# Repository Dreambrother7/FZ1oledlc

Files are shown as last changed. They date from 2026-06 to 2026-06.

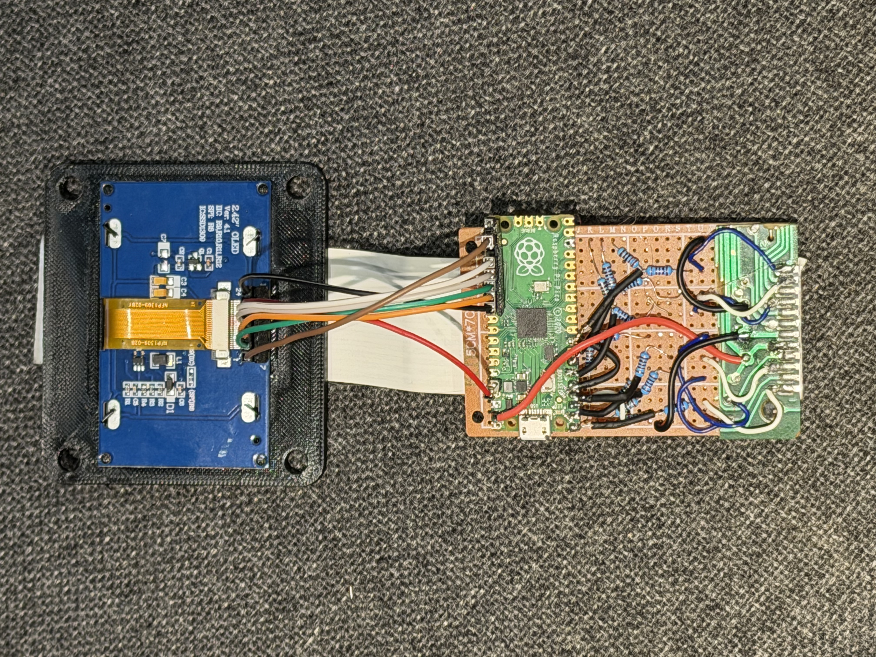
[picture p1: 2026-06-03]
images/Pico and display wiring.jpeg

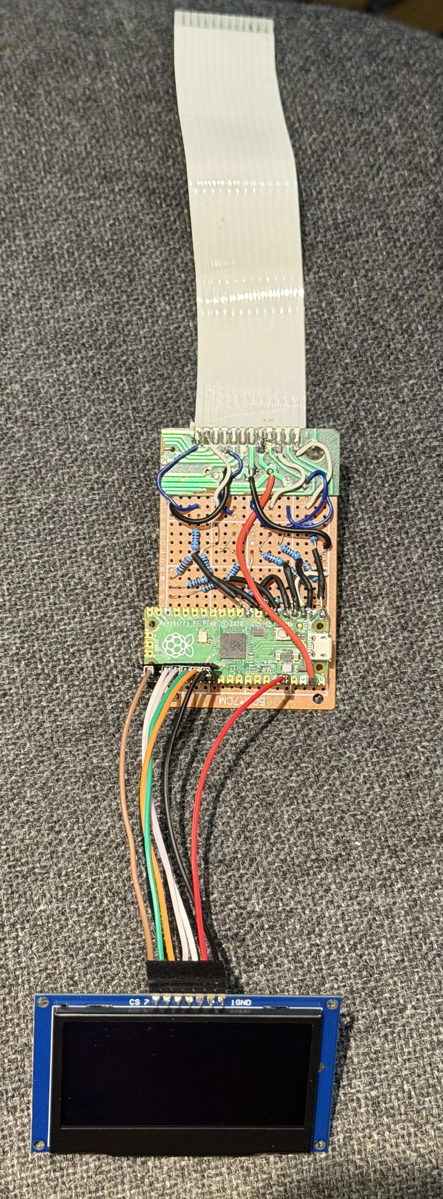
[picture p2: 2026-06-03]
images/Full display adapter.jpeg

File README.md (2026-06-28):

# Casio FZ-Series OLED Display Replacement

A low cost DIY replacement display for the Casio FZ-1, FZ-10M, FZ-20M, and related VZ-series devices using a Raspberry Pi Pico and a generic SSD1309 OLED module.

This project replaces the original ageing Casio FZ-series LCD with inexpensive, readily available parts. The goal is to make the repair practical and affordable for ordinary owners: no rare display module, no specialist programmable logic, and no expensive donor parts. There are now two supported build methods: a hand-wired version using a 3D printed OLED mount, and a Deftaudio PCB version that carries the Pico and OLED on a purpose-made board.

> Project status: working prototype for Casio FZ-series hardware. The firmware renders correctly on tested FZ hardware, including Deftaudio PCB testing on FZ-1, FZ-10 / FZ-20 units. Related VZ-series support is planned for a future update but is not implemented yet. More long-term testing is still in progress. Please report any observed issues or unwanted behaviour.

## Current Revision

Documentation revision: `v0.2.0`

Recent additions since the original working prototype:

- Standalone OLED test firmware for checking the screen before connecting the FZ-1 display bus.
- Five-minute idle screensaver in the main FZ-1 display firmware.
- Deftaudio Pico OLED PCB support, including KiCad files and a ready-to-upload Gerber zip.
- Separate `original` and `deftaudio_pcb` firmware variants for the two hardware methods.
- Experimental Pico 2 / RP2350 builds. These build successfully, but should be treated as untested until confirmed on real hardware.

## Why This Exists

Many Casio FZ-1 units still sound wonderful, but the original display hardware is now a weak point. Replacement displays are difficult to source, and many modern display modules do not speak the same protocol as the original LCD.

This project keeps the synthesizer mostly original while replacing only the display system. The FZ-1 still drives its original display bus; the Pico listens to that bus, decodes the commands, and renders the same content onto a modern OLED.

## Why A Raspberry Pi Pico?

The RP2040 is especially well suited to this job because of its PIO peripheral.

The FZ-1 display bus is a timing-sensitive 4-bit parallel interface with separate clock, chip-enable, and command/data signals. A normal microcontroller interrupt loop can easily miss edges or jitter under load. The Pico's PIO state machine can sample the bus independently of the CPU, while DMA moves captured samples into memory. The main firmware can then decode and render the display data without needing to bit-bang the vintage bus directly.

In short:

- PIO gives reliable edge-triggered bus capture.
- DMA keeps capture overhead low.
- Hardware SPI drives the OLED quickly.
- The Pico is cheap, common, and easy to flash by copying a UF2 file.

## Repository Contents

- `main.cpp` - Main FZ-1 display firmware, protocol parser, renderer, and screensaver.
- `oled_ssd1309.cpp` / `oled_ssd1309.h` - Shared SSD1309 OLED driver.
- `oled_test.cpp` - Standalone OLED wiring/display test firmware.
- `fz1_capture.pio` - PIO program for sampling the FZ-1 display bus.
- `font.h` - 256-character FZ-compatible 6x8 font table.
- `FZ1wiring-original.md` - Wiring reference for the original hand-wired build and 3D printed mount.
- `FZ1wiring-deftaudio-pcb.md` - Wiring and bring-up reference for the Deftaudio PCB build.
- `images/` - Photos of the original display board, cut connector board, assembled electronics, and installed working display.
- `3D printed mount/` - STL files for printing the display mounting plate and brackets.
- `pcb/deftaudio_pico_oled/` - Deftaudio KiCad PCB project and exported Gerber/drill manufacturing files.
- `pcb/deftaudio_connector_adapters/` - Deftaudio KiCad projects and Gerber zips for optional FZ-series IDC connector adapter boards.

## Image References

- `images/Original display board.jpeg` - Original FZ-1 display board before modification.
- `images/Original connector before cutting.jpeg` - Original connector area before cutting the donor display board.
- `images/Pico and display wiring.jpeg` - Pico, OLED, and resistor divider wiring.
- `images/Full display adapter.jpeg` - Assembled display adapter wiring.
- `images/Boot logo.jpeg` - Working OLED showing the FZ-1 boot logo.
- `images/Main menu.jpeg` - Working OLED showing the FZ-1 main menu.

## Build Options

The Pico passively listens to the FZ-1 display bus. It does not replace or emulate the FZ-1 CPU; it only translates the original display traffic into SSD1309 OLED drawing commands.

There are two supported hardware approaches.

### Original Hand-Wired Method

This is the original prototype method. It reuses the FZ-1 display connector or a cut-down section of the original display board, wires the Pico by hand through resistor dividers, and mounts the OLED with the 3D printed parts in `3D printed mount/`.

Use:

- Wiring file: `FZ1wiring-original.md`
- Main firmware: `FZ1_display_original_*.uf2`
- OLED test firmware: `FZ1_oled_test_original_*.uf2`

### Deftaudio PCB Method

This method uses the Deftaudio Pico OLED PCB. The board can be ordered by uploading `pcb/deftaudio_pico_oled/Pico_FZ1_OLED_PCB_gerbers.zip` to a PCB manufacturer such as PCBWay or a similar service. The loose Gerber/drill files are also included in `pcb/deftaudio_pico_oled/export1.0/`. The Pico and OLED attach to the PCB, and the PCB assembly then mounts directly in the synth.

Deftaudio also provides optional IDC connector adapter boards for connecting the synth display harness to the Pico OLED PCB. The FZ-1 adapter and the FZ-10M/FZ-20M/VZ-10M adapter are included in `pcb/deftaudio_connector_adapters/`, each with KiCad source files and a ready-to-upload Gerber zip.

Use:

- Wiring file: `FZ1wiring-deftaudio-pcb.md`
- PCB files: `pcb/deftaudio_pico_oled/`
- Optional connector adapter PCB files: `pcb/deftaudio_connector_adapters/`
- Main firmware: `FZ1_display_deftaudio_pcb_*.uf2`
- OLED test firmware: `FZ1_oled_test_deftaudio_pcb_*.uf2`

## Firmware Variants

The two hardware methods need different firmware because the OLED wiring and physical orientation are not the same.

| Variant | Use this for | OLED DC/A0 | OLED RES/RST | OLED orientation |
| --- | --- | --- | --- | --- |
| `original` | Hand wiring and the 3D printed mount in this repository | GP20 | GP21 | Original orientation |
| `deftaudio_pcb` | First Deftaudio PCB layout based on the earlier wiring guide | GP21 | GP20 | Rotated 180 degrees |

Important: disconnect the Pico from USB when powering it from the FZ-1 `VSYS` connection, unless your hardware setup specifically prevents back-powering.

For Pico 2 testing, the firmware builds with `PICO_BOARD=pico2` using the same GP0-GP6 FZ-1 bus pin mapping. The OLED pin mapping still depends on the selected `original` or `deftaudio_pcb` firmware variant.

## Parts

Core parts for both methods:

- Raspberry Pi Pico or compatible RP2040 Pico board.
- Raspberry Pi Pico 2 for experimental RP2350 testing.
- 128x64 SPI OLED module using SSD1309 controller.

For the original hand-wired method:

- Casio FZ-1 with original display connector/board available.
- 1k and 2k resistors for voltage dividers on the FZ-1 bus signals.
- Hookup wire, soldering tools, and basic mounting hardware.
- 3D printed OLED mount and brackets from `3D printed mount/`.

For the Deftaudio PCB method:

- PCB ordered from `pcb/deftaudio_pico_oled/Pico_FZ1_OLED_PCB_gerbers.zip`.
- Optional connector adapter PCB ordered from the matching Gerber zip in `pcb/deftaudio_connector_adapters/`.
- Components and headers required by the Deftaudio PCB design.
- Soldering tools and mounting hardware appropriate to the PCB assembly.

The prototype uses resistor dividers rather than active level-shifter ICs. Bidirectional auto-sensing level shifters were originally tested and proved incompatible with the FZ-1 display bus.

Pico 2 / RP2350 builds are provided for experimenters, but they have not yet been confirmed on real FZ-1 hardware. If you are building the mod today, use the resistor-divider wiring shown in the wiring guide for your hardware method. Do not connect FZ-1 5V display-bus signals directly to any Pico 2 pin unless you have checked the exact board, power conditions, and GPIO limits against the official [RP2350 datasheet](https://pip.raspberrypi.com/documents/RP-008373-DS-2-rp2350-datasheet.pdf) and [Pico 2 datasheet](https://pip.raspberrypi.com/documents/RP-008299-DS-pico-2-datasheet.pdf). One concern is that the RP2350 pins are only 5V tolerant after power on and if the FZ pushes 5V to the pins before power on is complete, damage is possible.

## Physical Installation

For the original hand-wired method, the prototype reuses part of the original display board as a connector breakout. The original display PCB is cut so that the FZ-1 ribbon connector section can be retained, and wires are soldered to that retained connector section. The OLED is held in a custom 3D printed mount designed to match the shape of the display module and closely follow the original FZ-1 mounting plate.

For the Deftaudio PCB method, order the main board by uploading `pcb/deftaudio_pico_oled/Pico_FZ1_OLED_PCB_gerbers.zip`, assemble the Pico and OLED onto the PCB, then install the completed PCB assembly in the synth. If you want a PCB adapter for the synth-side display connector, order the matching board from `pcb/deftaudio_connector_adapters/`: one design is for FZ-1, and the other is for FZ-10M/FZ-20M/VZ-10M. This avoids the large point-to-point wiring loom used by the original prototype method.

Photos and installation references should be placed in `images/`. 3D printable files should be placed in `3D printed mount/`.

## Firmware Overview

The firmware has five main jobs:

1. Initialize the SSD1309 OLED over SPI.
2. Use PIO to sample the FZ-1 display bus on PH2 clock edges while #CE is active.
3. Decode the FZ-1 command/data packets.
4. Render text and graphics to the OLED using the FZ-1 font.
5. Enter a framebuffer-backed idle screensaver after five minutes without FZ-1 display content changes.

Implementation details:

- FZ-1 data lines are active-low.
- The physical data wiring is reversed, so decoded nibbles are bit-reversed with a lookup table.
- Hardware testing showed that each nibble is captured twice in adjacent pairs. The parser conservatively collapses packets only when every adjacent pair matches.
- The FZ-1 cursor arrow uses extended font glyph `0xEE`, so the renderer uses the full 256-entry font table.
- The screensaver draws a sparse twinkling star field, then restores the last real FZ-1 display image before processing new bus activity.

## Building The Firmware

Install the Raspberry Pi Pico SDK and an ARM embedded GCC toolchain. On macOS, the tested working setup for this project uses the `gcc-arm-embedded` Homebrew cask.

Configure and build:

```bash
cmake -S . -B build -DPICO_SDK_PATH=/path/to/pico-sdk
cmake --build build
```

The default Pico build produces:

```text
build/FZ1_display_original.uf2
build/FZ1_display_deftaudio_pcb.uf2
build/FZ1_oled_test_original.uf2
build/FZ1_oled_test_deftaudio_pcb.uf2
```

To build for Pico 2:

```bash
cmake -S . -B build-pico2 -DPICO_SDK_PATH=/path/to/pico-sdk -DPICO_BOARD=pico2
cmake --build build-pico2
```

That produces:

```text
build-pico2/FZ1_display_original.uf2
build-pico2/FZ1_display_deftaudio_pcb.uf2
build-pico2/FZ1_oled_test_original.uf2
build-pico2/FZ1_oled_test_deftaudio_pcb.uf2
```

## Flashing The Pico

The easiest route is to download a prebuilt UF2 file from the repository's GitHub Releases page:

- `FZ1_display_original_pico.uf2` - Main firmware for Raspberry Pi Pico using the original hand-wired method.
- `FZ1_display_deftaudio_pcb_pico.uf2` - Main firmware for Raspberry Pi Pico using the first Deftaudio PCB layout.
- `FZ1_oled_test_original_pico.uf2` - OLED wiring test for Raspberry Pi Pico using the original hand-wired method.
- `FZ1_oled_test_deftaudio_pcb_pico.uf2` - OLED wiring test for Raspberry Pi Pico using the first Deftaudio PCB layout.
- `FZ1_display_original_pico2.uf2` - Experimental main firmware for Raspberry Pi Pico 2 using the original hand-wired method.
- `FZ1_display_deftaudio_pcb_pico2.uf2` - Experimental main firmware for Raspberry Pi Pico 2 using the first Deftaudio PCB layout.
- `FZ1_oled_test_original_pico2.uf2` - OLED wiring test for Raspberry Pi Pico 2 using the original hand-wired method.
- `FZ1_oled_test_deftaudio_pcb_pico2.uf2` - OLED wiring test for Raspberry Pi Pico 2 using the first Deftaudio PCB layout.

If you are modifying the firmware, build it locally and use the UF2 produced in your build directory.

1. Hold the Pico `BOOTSEL` button while connecting it over USB.
2. The Pico appears as a USB mass-storage device.
3. Copy the correct `FZ1_oled_test_*.uf2` file first if you are doing display-side bring-up, or the correct `FZ1_display_*.uf2` file for normal use.
4. The Pico reboots automatically into the firmware.

Once installed in the FZ-1, the firmware is silent: there is no boot test pattern and no serial output.

Maintainers can create a GitHub Release by pushing a version tag such as `v0.1.0`. The release workflow builds Pico and Pico 2 UF2 files and attaches them to the release automatically.

## OLED Wiring Test Firmware

The repository builds a special OLED test firmware for each hardware method. Use it before connecting the FZ-1 display bus, or before installing the Deftaudio PCB assembly in the synth, to confirm that the Pico can drive the OLED correctly.

Choose the test firmware that matches the hardware:

- Original hand-wired build: `FZ1_oled_test_original_pico.uf2` or `FZ1_oled_test_original_pico2.uf2`
- Deftaudio PCB build: `FZ1_oled_test_deftaudio_pcb_pico.uf2` or `FZ1_oled_test_deftaudio_pcb_pico2.uf2`

The test firmware cycles through:

- A full-screen checkerboard.
- A text screen showing `FZ-1 OLED TEST`, the selected firmware variant, and `SSD1309 SPI OK`.
- A full-white screen.
- A blank screen.

If this test works but the main FZ-1 firmware does not, the OLED side is probably good and the next area to check is the FZ-1 bus connection or the selected firmware variant.

## Testing

Basic checks:

- OLED should clear at startup.
- FZ-1 boot screen should render correctly.
- Main menu text should be aligned and readable.
- Cursor arrow should appear and move with the FZ-1 cursor buttons.
- Switching pages and menus should not leave stale pixels or corrupt text.
- After five minutes without FZ-1 display content changes, the screen should switch to a sparse twinkling star field and then restore the previous FZ-1 screen on the next real display update.

If the display is blank, verify power, common ground, OLED SPI wiring, and reset/DC pins.

If the display is garbled, verify the FZ-1 bus wiring order, resistor dividers, and the GP0-GP6 contiguous capture wiring.

## Safety Notes

This modification requires opening the synthesizer and working near vintage electronics. Work carefully, disconnect power before soldering, and double-check the 5V-to-3.3V dividers before connecting the Pico.

Original Pico/RP2040 GPIOs are not 5V tolerant.

Pico 2/RP2350 direct 5V input testing is experimental. Do not assume that a wiring change is safe unless the exact board, power sequence, and GPIO limits have been checked against the official Raspberry Pi documentation.

## Credits

Special thanks to [Deftaudio](https://github.com/Deftaudio) for developing the Pico OLED PCB, allowing the PCB files to be hosted in this repository, and testing the Deftaudio PCB firmware on real Casio FZ-1, FZ-10, and FZ-20 hardware. That work makes the PCB build a much more practical option for other users.

This project was also developed with reference to the OLED upgrade material preserved in the [Deftaudio/Casio-FZ-1 repository](https://github.com/Deftaudio/Casio-FZ-1). Those files include a copy of the original AVR-based FZ/VZ OLED design by Dmitri Sytov, known as Dmitrins, who shared it on the [Yamahamusicians forum](https://yamahamusicians.com/forum/viewtopic.php?t=10666&start=240). The RP2040 firmware in this repository ports the concept to a Raspberry Pi Pico using PIO, DMA, and SPI.

## License

This project is released under the MIT License. See `LICENSE` for the full license text.

Third-party reference material is credited above and remains the work of its original authors.

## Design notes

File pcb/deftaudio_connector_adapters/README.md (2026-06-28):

# Deftaudio Connector Adapter PCBs

This folder contains Deftaudio's optional IDC connector adapter PCB designs for FZ-series OLED installations.

These boards are separate from the main Pico OLED PCB in `pcb/deftaudio_pico_oled/`. They provide model-specific connector adapter hardware for the synth-side display harness.

## Included Boards

| Folder | Use for | Upload-ready Gerber zip |
| --- | --- | --- |
| `fz1_oled_IDC_adapter_v2/` | Casio FZ-1 | `fz1_oled_IDC_adapter_v2_gerbers.zip` |
| `fz10m_fz20m_vz10m_oled_IDC_adapter/` | Casio FZ-10M, FZ-20M, and VZ-10M | `fz10m_fz20m_vz10m_oled_IDC_adapter_gerbers.zip` |

Each board folder includes the KiCad project files, local KiCad library files, loose Gerber/drill files in `export1.0/`, and a ready-to-upload Gerber zip for PCB manufacturers such as PCBWay.

Use the connector adapter that matches the synth model. The main firmware variant for the Deftaudio PCB method is still `deftaudio_pcb`.

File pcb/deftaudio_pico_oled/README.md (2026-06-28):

# Deftaudio Pico OLED PCB

This folder contains the Deftaudio Pico OLED PCB files for the Casio FZ-1 OLED replacement.

## Contents

- `Pico_FZ1_OLED_PCB.kicad_pro` - KiCad project.
- `Pico_FZ1_OLED_PCB.kicad_sch` - KiCad schematic.
- `Pico_FZ1_OLED_PCB.kicad_pcb` - KiCad PCB layout.
- `Pico_FZ1_OLED_PCB_gerbers.zip` - Ready-to-upload Gerber/drill package for PCB manufacture.
- `libs/` - Local KiCad symbol/footprint support files included with the project.
- `export1.0/` - Gerber and drill files for PCB manufacture.

Upload `Pico_FZ1_OLED_PCB_gerbers.zip` to a PCB manufacturer such as PCBWay or a similar service. The loose files in `export1.0/` are included for inspection or regeneration.

Use the repository firmware variant named `deftaudio_pcb` with this board. The original hand-wired firmware is not pin/orientation compatible with this PCB.

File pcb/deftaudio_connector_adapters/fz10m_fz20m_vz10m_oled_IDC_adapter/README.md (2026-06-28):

# FZ-10M / FZ-20M / VZ-10M OLED IDC Adapter

This folder contains Deftaudio's FZ-10M, FZ-20M, and VZ-10M IDC connector adapter PCB design for the Pico OLED installation.

## Contents

- `fz10_oled_IDC_adapter.kicad_pro` - KiCad project.
- `fz10_oled_IDC_adapter.kicad_sch` - KiCad schematic.
- `fz10_oled_IDC_adapter.kicad_pcb` - KiCad PCB layout.
- `fz10m_fz20m_vz10m_oled_IDC_adapter_gerbers.zip` - Ready-to-upload Gerber/drill package for PCB manufacture.
- `export1.0/` - Loose Gerber and drill files.
- `libs/` - Local KiCad symbol/footprint support files included with the project.

Upload `fz10m_fz20m_vz10m_oled_IDC_adapter_gerbers.zip` to a PCB manufacturer such as PCBWay or a similar service.

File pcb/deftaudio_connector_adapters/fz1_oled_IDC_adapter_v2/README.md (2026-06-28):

# FZ-1 OLED IDC Adapter v2

This folder contains Deftaudio's FZ-1 IDC connector adapter PCB design for the Pico OLED installation.

## Contents

- `fz1_oled_IDC_adapter.kicad_pro` - KiCad project.
- `fz1_oled_IDC_adapter.kicad_sch` - KiCad schematic.
- `fz1_oled_IDC_adapter.kicad_pcb` - KiCad PCB layout.
- `fz1_oled_IDC_adapter_v2_gerbers.zip` - Ready-to-upload Gerber/drill package for PCB manufacture.
- `export1.0/` - Loose Gerber and drill files.
- `libs/` - Local KiCad symbol/footprint support files included with the project.

Upload `fz1_oled_IDC_adapter_v2_gerbers.zip` to a PCB manufacturer such as PCBWay or a similar service.

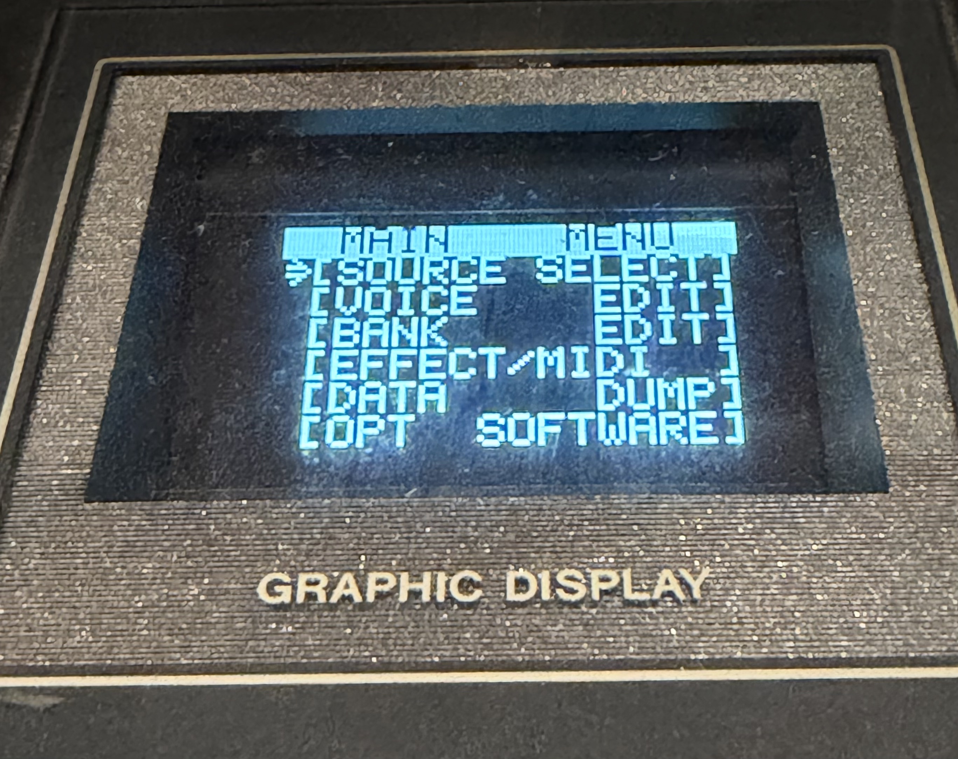
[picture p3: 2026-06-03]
images/Main menu.jpeg

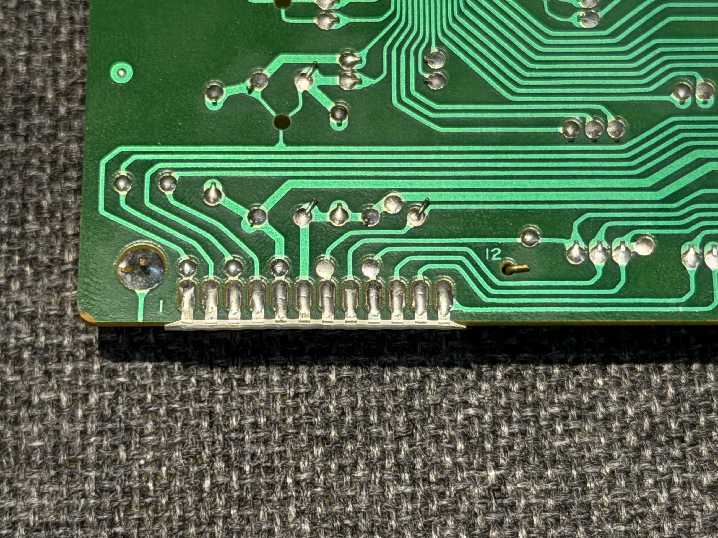
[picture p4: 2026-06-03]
images/Original connector before cutting.jpeg

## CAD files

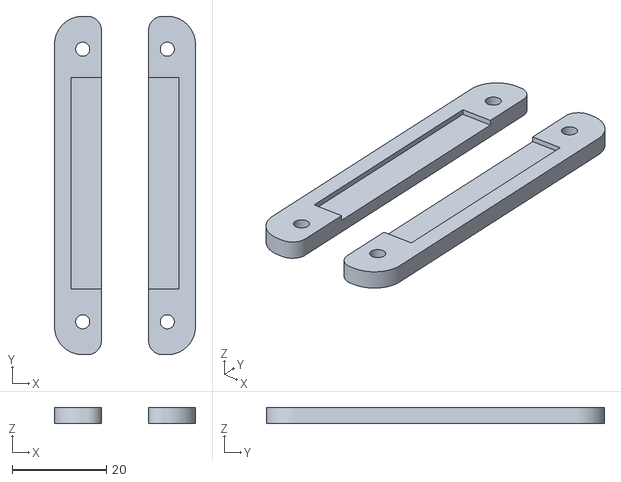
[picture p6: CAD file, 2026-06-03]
3D printed mount/FZ1OLEDbrackets.stl
30.0 x 72.0 x 3.50

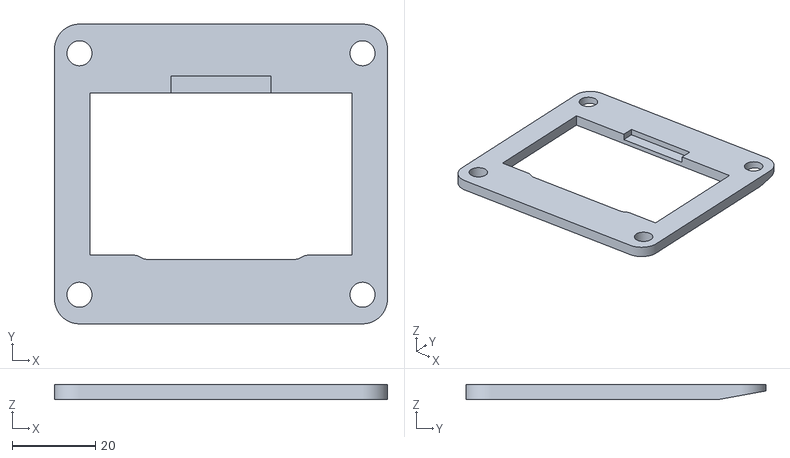
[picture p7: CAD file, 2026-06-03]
3D printed mount/FZ1OLEDmount.stl
80.0 x 72.0 x 3.50

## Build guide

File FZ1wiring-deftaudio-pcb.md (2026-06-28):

# Deftaudio PCB Build Wiring

This wiring reference is for the Deftaudio Pico OLED PCB method. The PCB files are in `pcb/deftaudio_pico_oled/`.

Use the `deftaudio_pcb` firmware files with this board.

## What The PCB Does

The Deftaudio PCB replaces most of the point-to-point wiring used by the original hand-wired build. It provides footprints/connectors for:

- Raspberry Pi Pico or Pico 2.
- SSD1309 128x64 SPI OLED module.
- FZ-1 display connector/header connection.
- The resistor-divider network used to bring FZ-1 5V bus signals down to Pico-safe logic levels.

The PCB layout mounts the OLED inverted compared with the original hand-wired build. It also routes OLED DC/A0 and RES/RST differently from the original wiring. The `deftaudio_pcb` firmware variant handles both differences in software by swapping the OLED control pins and rotating the SSD1309 output 180 degrees.

Optional synth-side IDC connector adapter boards are included in `pcb/deftaudio_connector_adapters/`:

- `fz1_oled_IDC_adapter_v2/` - FZ-1 connector adapter.
- `fz10m_fz20m_vz10m_oled_IDC_adapter/` - FZ-10M, FZ-20M, and VZ-10M connector adapter.

These adapter boards are separate from the main Pico OLED PCB. Use the adapter that matches the synth model you are installing into.

## PCB Files

The KiCad project is in:

```text
pcb/deftaudio_pico_oled/
```

The ready-to-upload manufacturing files are in:

```text
pcb/deftaudio_pico_oled/Pico_FZ1_OLED_PCB_gerbers.zip
```

The same Gerber and drill files are also available loose in:

```text
pcb/deftaudio_pico_oled/export1.0/
```

The zip file is the simplest option for PCB manufacturers such as PCBWay or similar board houses.

Optional connector adapter manufacturing zips are in:

```text
pcb/deftaudio_connector_adapters/fz1_oled_IDC_adapter_v2/fz1_oled_IDC_adapter_v2_gerbers.zip
pcb/deftaudio_connector_adapters/fz10m_fz20m_vz10m_oled_IDC_adapter/fz10m_fz20m_vz10m_oled_IDC_adapter_gerbers.zip
```

## FZ Display-Bus Header

The PCB FZ display-bus connector is `J2`, a 2x5 2.00 mm header in the KiCad files.

| J2 pin | PCB net | Function |
| --- | --- | --- |
| 1 | D4 | FZ display data D4 |
| 2 | D8 | FZ display data D8 |
| 3 | D1 | FZ display data D1 |
| 4 | D2 | FZ display data D2 |
| 5 | GND | Ground |
| 6 | +5 | FZ +5V supply |
| 7 | CE | FZ display chip enable |
| 8 | RH2 | FZ PH2 display clock; labelled `RH2` in the PCB files |
| 9 | GND | Ground |
| 10 | OP | FZ command/data select |

The PCB includes the resistor-divider network for the FZ 5V display-bus signals. The divided Pico-side nets route to the firmware capture pins as follows:

| FZ signal | Pico GPIO |
| --- | --- |
| D8 | GP0 |
| D4 | GP1 |
| D2 | GP2 |
| D1 | GP3 |
| PH2 clock / `RH2` PCB net | GP4 |
| CE | GP5 |
| OP | GP6 |

## OLED Header

The PCB OLED header is `J1`, a 1x7 2.54 mm header in the KiCad files. It is labelled for the OLED module signals:

| J1 pin | PCB/OLED signal | Pico GPIO | Purpose |
| --- | --- | --- | --- |
| 1 | GND | GND | Ground |
| 2 | 3.3V | 3V3_OUT | OLED power from Pico 3V3 |
| 3 | SCK | GP18 | SPI clock |
| 4 | SDA | GP19 | SPI MOSI data |
| 5 | RES | GP20 | OLED reset |
| 6 | DC | GP21 | OLED data/command |
| 7 | CS | GP17 | OLED chip select |

Because this board uses the Deftaudio routing and physical orientation, do not flash the `original` firmware for this method.

## Bring-Up Checklist

- Inspect the assembled board for solder bridges before installing it in the FZ-1.
- Confirm Pico orientation and OLED orientation against the PCB silkscreen/KiCad files before soldering.
- Flash `FZ1_oled_test_deftaudio_pcb_*.uf2` first and power only the Pico/OLED side to confirm the display works.
- The OLED test should cycle through checkerboard, text, white, and blank screens.
- After the OLED test passes, flash `FZ1_display_deftaudio_pcb_*.uf2`.
- Install/connect the board in the FZ-1 only after the display-side test is working.

Disconnect the Pico USB cable when powering the Pico from the FZ-1 unless your setup specifically prevents back-powering.

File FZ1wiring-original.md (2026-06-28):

# Original Hand-Wired Build Wiring

This wiring reference is for the original build method: reuse the FZ-1 display connector or connector section, wire the Pico by hand, and mount the OLED with the 3D printed parts in `3D printed mount/`.

Use the `original` firmware files with this wiring.

## FZ-1 Bus Capture

All FZ-1 bus signals are 5V logic. Each signal connected to the Pico must pass through a resistor divider:

1. Connect a 1k resistor from the FZ-1 signal to the Pico GPIO.
2. Connect a 2k resistor from that Pico GPIO to ground.

The Pico GPIOs must remain contiguous on GP0-GP6 because the PIO state machine samples them together.

| FZ-1 pin | FZ-1 signal | Divider output to Pico |
| --- | --- | --- |
| Pin 1 | D8 | GP0 |
| Pin 2 | D4 | GP1 |
| Pin 3 | D2 | GP2 |
| Pin 4 | D1 | GP3 |
| Pin 9 | PH2 clock | GP4 |
| Pin 11 | #CE | GP5 |
| Pin 12 | #OP | GP6 |

## OLED SPI

These connections are 3.3V logic and wire directly from the Pico to the SSD1309 OLED.

| OLED signal | Pico GPIO |
| --- | --- |
| CS | GP17 |
| SCK / SCL / D0 | GP18 |
| MOSI / SDA / D1 | GP19 |
| DC / A0 | GP20 |
| RES / RST | GP21 |

## Power

| Source | Destination | Purpose |
| --- | --- | --- |
| FZ-1 +5V | Pico VSYS | Pico power |
| Pico 3V3_OUT | OLED VCC / VDD | OLED power |
| FZ-1 GND | Pico GND and OLED GND | Common ground |

Disconnect the Pico USB cable when powering the Pico from FZ-1 VSYS unless your setup specifically prevents back-powering.

## Bench Checklist

- Verify about 5V on the FZ-1 power pin before connecting the Pico.
- Verify every resistor-divider output is around 3.3V or lower before connecting it to the Pico.
- Confirm GP0-GP6 are in the exact order shown above.
- Flash `FZ1_oled_test_original_*.uf2` and confirm the OLED test pattern before connecting the FZ-1 display bus.
- After the OLED test passes, flash `FZ1_display_original_*.uf2` for normal use.

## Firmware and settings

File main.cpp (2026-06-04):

#include "pico/stdlib.h"
#include "hardware/dma.h"
#include "hardware/pio.h"
#include "fz1_capture.pio.h"
#include "font.h"
#include "oled_ssd1309.h"

// FZ-1 Input pins start at GP0
#define FZ1_PIN_BASE 0
#define FZ1_PIN_COUNT 7

// FZ-1 Protocol
#define FZ_GRAPHIC  0x02
#define FZ_TEXT     0x03
#define FZ_CONTRAST 0x0C
#define FZ_RESET    0x0A

#define HORIZONTAL_OFFSET 3
#define PACKET_GAP_US 2000
#define PACKET_IDLE_FLUSH_US 50000
#define SCREENSAVER_IDLE_US (5ULL * 60ULL * 1000ULL * 1000ULL)
#define SCREENSAVER_FRAME_US 90000

// Nibble bit-reversal LUT (matching reference nibbleflip)
static const uint8_t nibbleflip[16] = {
    0x00, 0x08, 0x04, 0x0C, 0x02, 0x0A, 0x06, 0x0E,
    0x01, 0x09, 0x05, 0x0D, 0x03, 0x0B, 0x07, 0x0F
};

// Text memory for XOR operations
static uint8_t text_mem[8][24];
static uint8_t display_buf[OLED_PAGES][OLED_WIDTH];

// State from last command packet
static uint8_t last_cmd = 0;
static uint8_t last_flags = 0;
static uint8_t last_col = 0;
static uint8_t last_row = 0;

static uint32_t rng_state = 0x4F4C4544u;
static uint64_t last_display_change_time = 0;
static bool screensaver_active = false;

static uint32_t rand32() {
    rng_state ^= rng_state << 13;
    rng_state ^= rng_state >> 17;
    rng_state ^= rng_state << 5;
    return rng_state;
}

static void display_restore();

static void display_write(uint8_t page, uint8_t col, const uint8_t* data, uint8_t len) {
    if (page >= OLED_PAGES || col >= OLED_WIDTH || len == 0) {
        return;
    }
    if (col + len > OLED_WIDTH) {
        len = OLED_WIDTH - col;
    }

    bool changed = false;
    for (uint8_t i = 0; i < len; i++) {
        if (display_buf[page][col + i] != data[i]) {
            changed = true;
        }
        display_buf[page][col + i] = data[i];
    }

    if (changed) {
        last_display_change_time = time_us_64();
    }

    if (screensaver_active) {
        if (changed) {
            screensaver_active = false;
            display_restore();
        }
        return;
    }

    oled_write(page, col, data, len);
}

static void display_restore() {
    for (uint8_t page = 0; page < OLED_PAGES; page++) {
        oled_write(page, 0, display_buf[page], OLED_WIDTH);
    }
}

static void display_clear_state() {
    for (int page = 0; page < OLED_PAGES; page++) {
        for (int col = 0; col < OLED_WIDTH; col++) {
            display_buf[page][col] = 0;
        }
    }
    for (int y = 0; y < 8; y++) {
        for (int j = 0; j < 24; j++) {
            text_mem[y][j] = ' ';
        }
    }
    oled_clear();
    last_display_change_time = time_us_64();
}

static void screensaver_frame() {
    uint8_t page_buf[OLED_WIDTH];

    for (uint8_t page = 0; page < OLED_PAGES; page++) {
        for (uint8_t col = 0; col < OLED_WIDTH; col++) {
            uint8_t stars = 0;
            if ((rand32() & 0x0F) == 0) {
                stars = 1u << (rand32() & 0x07);
            }
            if ((rand32() & 0x3F) == 0) {
                stars |= 1u << (rand32() & 0x07);
            }
            page_buf[col] = stars;
        }
        oled_write(page, 0, page_buf, sizeof(page_buf));
    }
}

// ===== FZ-1 Display Functions (matching reference) =====

// Column mapping: remove the gap in the middle of the FZ-1's address space
static uint8_t calc_column(uint8_t col) {
    uint8_t col1 = col >> 1;
    uint8_t column = (col1 & 64) ? col1 : col1 + 16;
    return column + HORIZONTAL_OFFSET;
}

void display_char_fz1(uint8_t row, uint8_t col, uint8_t chr) {
    if (row >= 8 || (col / 12) >= 24) {
        return;
    }

    uint8_t column = calc_column(col);
    uint8_t page = 7 - row;

    display_write(page, column, (const uint8_t*)font[chr], 6);
    text_mem[row][col / 12] = chr;
}

void display_new_fz1(uint8_t row, uint8_t col, const uint8_t* data, uint8_t len) {
    if (row >= 8) {
        return;
    }

    uint8_t column = calc_column(col);
    uint8_t page = 7 - row;

    display_write(page, column, data, len);
}

void display_xor_fz1(uint8_t row, uint8_t col, const uint8_t* data, uint8_t len) {
    if (row >= 8 || (col / 12) >= 24) {
        return;
    }

    uint8_t column = calc_column(col);
    uint8_t page = 7 - row;
    uint8_t ch = text_mem[row][col / 12];

    uint8_t xor_buf[6];
    uint8_t xlen = (len < 6) ? len : 6;
    for (int x = 0; x < xlen; x++) {
        xor_buf[x] = font[ch][x] ^ data[x];
    }
    display_write(page, column, xor_buf, xlen);
}

// ===== FZ-1 Protocol Handlers =====

void process_command_packet(const uint8_t* nibbles, uint32_t len) {
    if (len < 6) {
        return;
    }

    // Nibbles: [0]=CMD, [1]=FLAGS, [2]=COLL, [3]=COLH, [4]=ROWL, [5]=ROWH
    last_cmd   = nibbles[0];
    last_flags = nibbles[1];
    last_col   = nibbles[2] | (nibbles[3] << 4);
    last_row   = nibbles[4] | (nibbles[5] << 4);

    // Row adjustment from flags (reference: if bit0 set and row < 4, add 4)
    if ((last_flags & 0x01) && last_row < 4)
        last_row += 4;

    // Command phase only stores parameters.
    // Character codes and graphic data arrive in the subsequent data phase.
}

void process_data_packet(const uint8_t* nibbles, uint32_t len) {
    if (len < 2) {
        return;
    }

    if (last_cmd == FZ_TEXT) {
        // Text data: 2 nibbles = character code
        uint8_t chr = nibbles[0] | (nibbles[1] << 4);
        display_char_fz1(last_row, last_col, chr);

    } else if (last_cmd == FZ_GRAPHIC) {
        // Graphic data: pairs of nibbles = pixel bytes
        uint32_t byte_len = len / 2;
        if (byte_len > 128) byte_len = 128;

        uint8_t data_bytes[128];
        for (uint32_t i = 0; i < byte_len; i++) {
            data_bytes[i] = (nibbles[i * 2] << 4) | nibbles[i * 2 + 1];
        }

        bool operation = (last_flags & 0x08) != 0;

        if (operation) {
            display_new_fz1(last_row, last_col, data_bytes, byte_len);
        } else {
            display_xor_fz1(last_row, last_col, data_bytes, byte_len);
        }
    }
}

static bool collapse_duplicated_nibbles(const uint8_t* src, uint32_t src_len, uint8_t* dst, uint32_t* dst_len) {
    if (src_len < 2 || (src_len & 1)) return false;

    for (uint32_t i = 0; i < src_len; i += 2) {
        if ((src[i] & 0x0F) != (src[i + 1] & 0x0F)) return false;
    }

    for (uint32_t i = 0; i < src_len / 2; i++) {
        dst[i] = src[i * 2];
    }
    *dst_len = src_len / 2;
    return true;
}

static void flush_packet(bool is_command_mode, const uint8_t* packet_buf, uint32_t packet_len) {
    if (packet_len == 0) return;

    static uint8_t collapsed_packet_buf[4096];
    const uint8_t* parse_buf = packet_buf;
    uint32_t parse_len = packet_len;

    if (collapse_duplicated_nibbles(packet_buf, packet_len, collapsed_packet_buf, &parse_len)) {
        parse_buf = collapsed_packet_buf;
    }

    if (is_command_mode) {
        process_command_packet(parse_buf, parse_len);
    } else {
        process_data_packet(parse_buf, parse_len);
    }
}

// ===== DMA Ring Buffer =====

#define RING_BUF_SIZE 32768
uint8_t ring_buf[RING_BUF_SIZE] __attribute__((aligned(RING_BUF_SIZE)));
int dma_chan;

void dma_init_ring(PIO pio, uint sm) {
    dma_chan = dma_claim_unused_channel(true);
    dma_channel_config c = dma_channel_get_default_config(dma_chan);

    channel_config_set_transfer_data_size(&c, DMA_SIZE_8);
    channel_config_set_read_increment(&c, false);
    channel_config_set_write_increment(&c, true);
    channel_config_set_dreq(&c, pio_get_dreq(pio, sm, false));
    channel_config_set_ring(&c, true, 15);

    dma_channel_configure(
        dma_chan,
        &c,
        ring_buf,
        (volatile uint8_t*)&pio->rxf[sm],
        0xFFFFFFFF,
        true
    );
}

// ===== Main =====

int main() {
    oled_init();
    display_clear_state();

    PIO pio = pio0;
    uint sm = 0;
    uint offset = pio_add_program(pio, &fz1_capture_program);
    fz1_capture_program_init(pio, sm, offset, 0, 7);

    pio_sm_set_enabled(pio, sm, true);
    dma_init_ring(pio, sm);

    bool is_command_mode = true;
    bool packet_active = false;
    uint32_t packet_len = 0;
    static uint8_t local_packet_buf[8192];
    uint64_t last_nibble_time = time_us_64();
    uint64_t last_screensaver_frame_time = 0;
    uint32_t ring_tail = 0;
    last_display_change_time = last_nibble_time;

    while (true) {
        uint64_t now = time_us_64();
        uint32_t ring_head = ((uint32_t)dma_hw->ch[dma_chan].write_addr - (uint32_t)ring_buf);

        if (ring_tail != ring_head) {
            uint8_t raw_sample = ring_buf[ring_tail];
            ring_tail = (ring_tail + 1) % RING_BUF_SIZE;

            uint8_t payload = raw_sample & 0x7F;

            // Decode nibble: bit-reverse (Pin1=D8→GP0, Pin4=D1→GP3) then invert (active-low)
            // Using the same nibbleflip LUT as the reference implementation
            uint8_t decoded_nibble = nibbleflip[(~payload) & 0x0F];

            // GP6 = #OP: LOW (0) = command mode, HIGH (1) = data mode
            bool current_is_command = ((payload >> 6) & 0x01) == 0;

            if (packet_active && (now - last_nibble_time > PACKET_GAP_US)) {
                flush_packet(is_command_mode, local_packet_buf, packet_len);
                packet_active = false;
                packet_len = 0;
            }

            // Detect mode change → process previous packet
            if (packet_active && current_is_command != is_command_mode) {
                flush_packet(is_command_mode, local_packet_buf, packet_len);
                packet_len = 0;
            }

            is_command_mode = current_is_command;
            packet_active = true;

            if (packet_len < sizeof(local_packet_buf)) {
                local_packet_buf[packet_len++] = decoded_nibble;
            }
            last_nibble_time = now;

        } else if (packet_active && (now - last_nibble_time > PACKET_IDLE_FLUSH_US)) {
            // Timeout → flush packet
            flush_packet(is_command_mode, local_packet_buf, packet_len);
            packet_active = false;
            packet_len = 0;
        } else if (!packet_active && now - last_display_change_time > SCREENSAVER_IDLE_US) {
            if (!screensaver_active || now - last_screensaver_frame_time > SCREENSAVER_FRAME_US) {
                screensaver_frame();
                screensaver_active = true;
                last_screensaver_frame_time = now;
            }
        }
    }
}

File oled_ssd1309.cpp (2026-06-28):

#include "oled_ssd1309.h"

#include "hardware/spi.h"
#include "pico/stdlib.h"

// SPI OLED Definitions (SSD1309)
#define SPI_PORT spi0

#ifndef OLED_PIN_CS
#define OLED_PIN_CS   17
#endif
#ifndef OLED_PIN_SDA
#define OLED_PIN_SDA  19
#endif
#ifndef OLED_PIN_SCL
#define OLED_PIN_SCL  18
#endif
#ifndef OLED_PIN_DC
#define OLED_PIN_DC   20
#endif
#ifndef OLED_PIN_RES
#define OLED_PIN_RES  21
#endif
#ifndef OLED_ROTATE_180
#define OLED_ROTATE_180 0
#endif

// SSD1309 Commands
#define OLED_DISPLAYOFF       0xAE
#define OLED_DISPLAYON        0xAF
#define OLED_SETCONTRAST      0x81
#define OLED_NORMALDISPLAY    0xA6
#define OLED_DISPLAYALLON_RESUME 0xA4
#define OLED_SETMULTIPLEX     0xA8
#define OLED_SETDISPLAYOFFSET 0xD3
#define OLED_SETDISPLAYCLOCKDIV 0xD5
#define OLED_SETPRECHARGE     0xD9
#define OLED_SETCOMPINS       0xDA
#define OLED_SETVCOMDETECT    0xDB
#define OLED_SETSTARTLINE     0x40
#define OLED_SEGREMAP         0xA0
#define OLED_SEGREMAP_INV     0xA1
#define OLED_COMSCANINC       0xC0
#define OLED_COMSCANDEC       0xC8
#define OLED_PAGEADDRSET      0xB0
#define OLED_COLUMNADDRSETH   0x10
#define OLED_COLUMNADDRSETL   0x00

void oled_send_cmd(uint8_t cmd) {
    gpio_put(OLED_PIN_CS, 0);
    gpio_put(OLED_PIN_DC, 0);
    spi_write_blocking(SPI_PORT, &cmd, 1);
    gpio_put(OLED_PIN_CS, 1);
}

void oled_send_data(uint8_t data) {
    gpio_put(OLED_PIN_CS, 0);
    gpio_put(OLED_PIN_DC, 1);
    spi_write_blocking(SPI_PORT, &data, 1);
    gpio_put(OLED_PIN_CS, 1);
}

void oled_send_data_buf(const uint8_t *buf, size_t len) {
    gpio_put(OLED_PIN_CS, 0);
    gpio_put(OLED_PIN_DC, 1);
    spi_write_blocking(SPI_PORT, buf, len);
    gpio_put(OLED_PIN_CS, 1);
}

void oled_set_cursor(uint8_t page, uint8_t col) {
    oled_send_cmd(OLED_PAGEADDRSET | page);
    oled_send_cmd(OLED_COLUMNADDRSETL | (col & 0x0F));
    oled_send_cmd(OLED_COLUMNADDRSETH | ((col >> 4) & 0x0F));
}

void oled_init() {
    spi_init(SPI_PORT, 10 * 1000 * 1000);
    gpio_set_function(OLED_PIN_SDA, GPIO_FUNC_SPI);
    gpio_set_function(OLED_PIN_SCL, GPIO_FUNC_SPI);
    gpio_init(OLED_PIN_CS); gpio_set_dir(OLED_PIN_CS, GPIO_OUT); gpio_put(OLED_PIN_CS, 1);
    gpio_init(OLED_PIN_DC); gpio_set_dir(OLED_PIN_DC, GPIO_OUT); gpio_put(OLED_PIN_DC, 0);
    gpio_init(OLED_PIN_RES); gpio_set_dir(OLED_PIN_RES, GPIO_OUT);

    gpio_put(OLED_PIN_RES, 1); sleep_ms(1);
    gpio_put(OLED_PIN_RES, 0); sleep_ms(15);
    gpio_put(OLED_PIN_RES, 1); sleep_ms(15);

    oled_send_cmd(OLED_DISPLAYOFF);

    oled_send_cmd(0xAD);  // Master Configuration
    oled_send_cmd(0x8E);  // External VCC

    oled_send_cmd(OLED_SETMULTIPLEX);
    oled_send_cmd(0x3F);  // 1/64 duty

    oled_send_cmd(OLED_SETDISPLAYOFFSET);
    oled_send_cmd(0x00);

    oled_send_cmd(OLED_SETSTARTLINE | 0x00);

    oled_send_cmd(OLED_NORMALDISPLAY);

    oled_send_cmd(OLED_SETVCOMDETECT);
    oled_send_cmd(0x3C);  // ~0.83xVCC

    oled_send_cmd(OLED_DISPLAYALLON_RESUME);

    oled_send_cmd(OLED_SETCONTRAST);
    oled_send_cmd(0x6F);

    oled_send_cmd(OLED_SETDISPLAYCLOCKDIV);
    oled_send_cmd(0xF0);  // 105Hz

    oled_send_cmd(0xD8);  // Area Color mode
    oled_send_cmd(0x05);  // Mono + low power

    oled_send_cmd(OLED_SETCOMPINS);
    oled_send_cmd(0x12);  // Alternative COM

    oled_send_cmd(OLED_SETPRECHARGE);
    oled_send_cmd(0xF2);
    oled_send_cmd(0xFF);

    oled_send_cmd(OLED_DISPLAYON);
#if OLED_ROTATE_180
    oled_send_cmd(OLED_COMSCANINC);
    oled_send_cmd(OLED_SEGREMAP_INV);
#else
    oled_send_cmd(OLED_COMSCANDEC);
    oled_send_cmd(OLED_SEGREMAP);
#endif

    sleep_ms(100);
}

void oled_write(uint8_t page, uint8_t col, const uint8_t *data, size_t len) {
    if (page >= OLED_PAGES || col >= OLED_WIDTH || len == 0) {
        return;
    }
    if (col + len > OLED_WIDTH) {
        len = OLED_WIDTH - col;
    }

    oled_set_cursor(page, col);
    oled_send_data_buf(data, len);
}

void oled_fill(uint8_t value) {
    uint8_t buf[OLED_WIDTH];
    for (int i = 0; i < OLED_WIDTH; i++) {
        buf[i] = value;
    }

    for (int page = 0; page < OLED_PAGES; page++) {
        oled_write(page, 0, buf, sizeof(buf));
    }
}

void oled_clear() {
    oled_fill(0x00);
}

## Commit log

2026-06-02 Update OLED wiring note
2026-06-03 Add alternate connector README notes
2026-06-03 Prepare assets for public repository
    [FZ1OLEDbrackets.stl, FZ1OLEDmount.stl]
2026-06-28 Prepare v0.2.0 release
    [Pico_FZ1_OLED_PCB-B_Cu.gbr, Pico_FZ1_OLED_PCB-B_Mask.gbr, Pico_FZ1_OLED_PCB-B_Paste.gbr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]
2026-06-28 Add Deftaudio connector adapter PCBs
    [fz10_oled_IDC_adapter-B_Cu.gbr, fz10_oled_IDC_adapter-B_Mask.gbr, fz10_oled_IDC_adapter-B_Paste.gbr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]
